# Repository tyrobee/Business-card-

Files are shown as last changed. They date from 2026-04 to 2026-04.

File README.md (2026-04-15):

# Business-card-
A PCB Business card
A personal Business Card designed as a PCB. It contains an integrated NFC tag to share contact information wirelessly, and uses energy harvesting from NFC field to light up the LED circuitry.The heart of this PCB is the NFC controller IC, the NT3H1101 from NXP Semiconductors.NFC (Near Field Communication) is a short-range radio technology that enables communication between devices that are held in close proximity (< 10 cm). NFC systems are based on traditional High Frequency (HF) RFID, operating at 13.56 MHz.The form factor is maintained as a standard credit/debit card, so you can carry it around normally in your wallet.I used the "Bitmap to Component Convertor" tool built in KiCAD to import my custom font text, Logo, QR code, etc. I imported them as Soldermask and Copper layer so that they'll be visible with nice HASL/ENIG finish. My suggestion would be to minimize the use of silkscreen, as the silkscreen print might not be of good quality for complex graphics.The NFC tag programming was done with Tagwriter app from NXP. This app has multiple options to write Website Links, Phone number, Email, etc into the NTAG IC which you can customize as per your requirement.

## Schematics
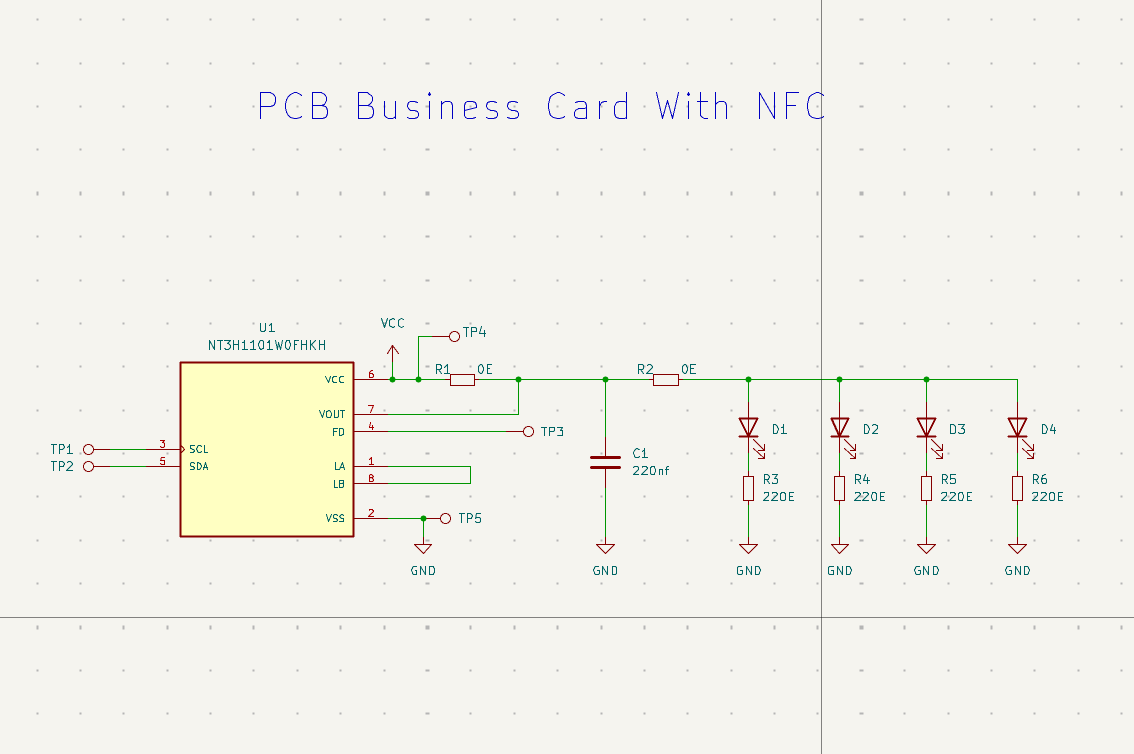
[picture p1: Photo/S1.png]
Back Design


## Pcb 
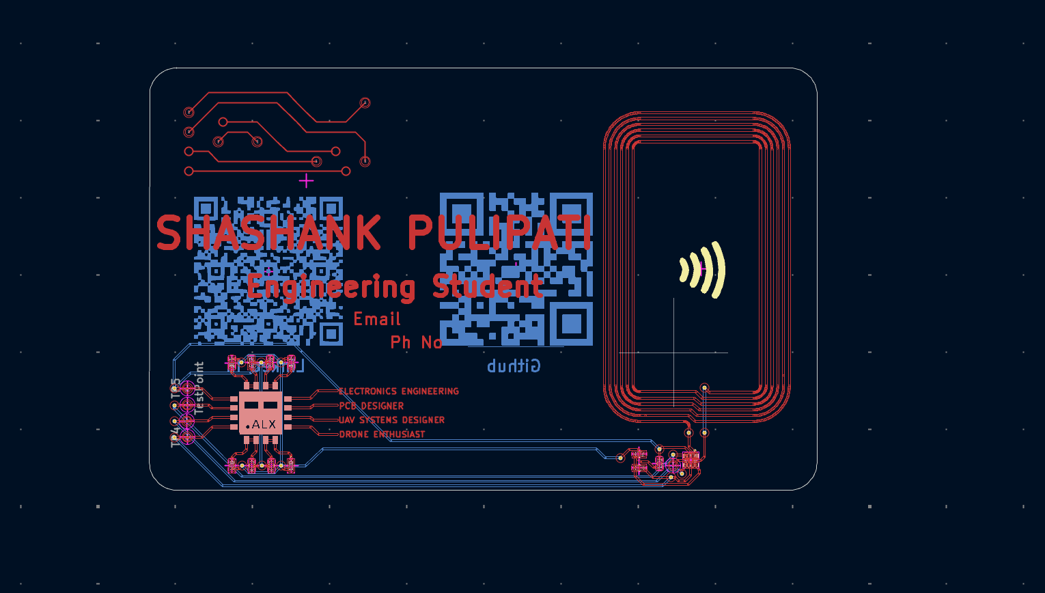
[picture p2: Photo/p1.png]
Front Design


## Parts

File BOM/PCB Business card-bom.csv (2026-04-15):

Name | Purpose | Quantity | Total Cost (USD) | Link | Distributor
pcb and pcba | pcb | 1 | 46.67 |  | jlcpcb

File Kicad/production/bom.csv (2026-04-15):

Designator | Footprint | Quantity | Value | LCSC Part #
C1 | 0402 | 1 | 220nf
D1, D2, D3, D4 | 0402 | 4 | LED
R1, R2 | 0402 | 2 | 0E
R3, R4, R5, R6 | 0402 | 4 | 220E
TP1, TP2, TP3, TP4, TP5 | TestPoint_Pad_D1.0mm | 5 | TestPoint
U1 | IC_NT3H1101W0FHKH | 1 | NT3H1101W0FHKH

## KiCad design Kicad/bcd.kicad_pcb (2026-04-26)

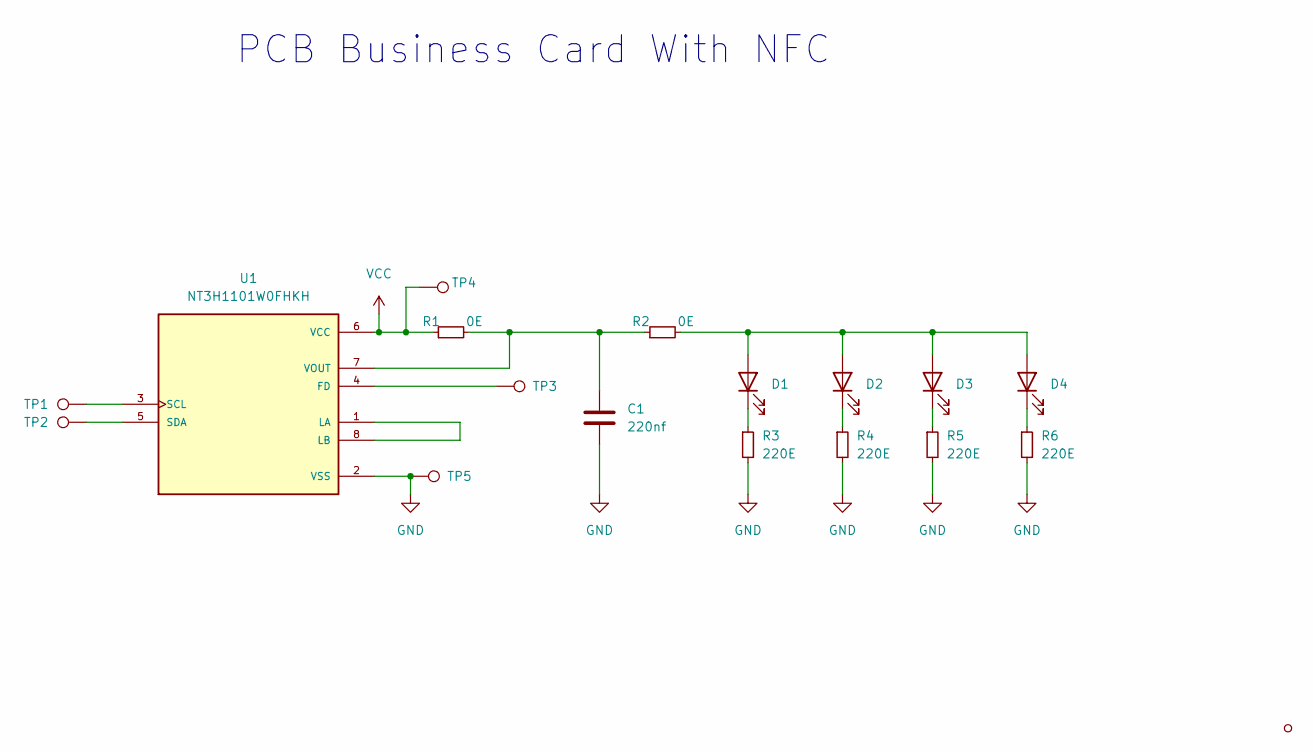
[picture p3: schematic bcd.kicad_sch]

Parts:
C1: 220nf; C_0402_1005Metric
D1, D2, D3, D4: LED; LED_0402_1005Metric
R1, R2: 0E; R_0402_1005Metric
R3, R4, R5, R6: 220E; R_0402_1005Metric
TP1, TP2, TP3, TP4, TP5: TestPoint; TestPoint_Pad_D1.0mm
TP6: TestPoint_Small
U1: NT3H1101W0FHKH; IC_NT3H1101W0FHKH; PARTREV 3.3

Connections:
GND: C1.2, R3.2, R4.2, R5.2, R6.2, TP5.1, U1.2 (VSS)
unnamed: C1.1, R1.2, R2.1, U1.7 (VOUT)
unnamed: D1.1 (K), R3.1
unnamed: D1.2 (A), D2.2 (A), D3.2 (A), D4.2 (A), R2.2
unnamed: D2.1 (K), R4.1
unnamed: D3.1 (K), R5.1
unnamed: D4.1 (K), R6.1
unnamed: TP1.1, U1.3 (SCL)
unnamed: TP2.1, U1.5 (SDA)
unnamed: TP3.1, U1.4 (FD)
unnamed: U1.1 (LA), U1.8 (LB)
VCC: R1.1, TP4.1, U1.6 (VCC)

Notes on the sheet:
PCB Business Card With NFC

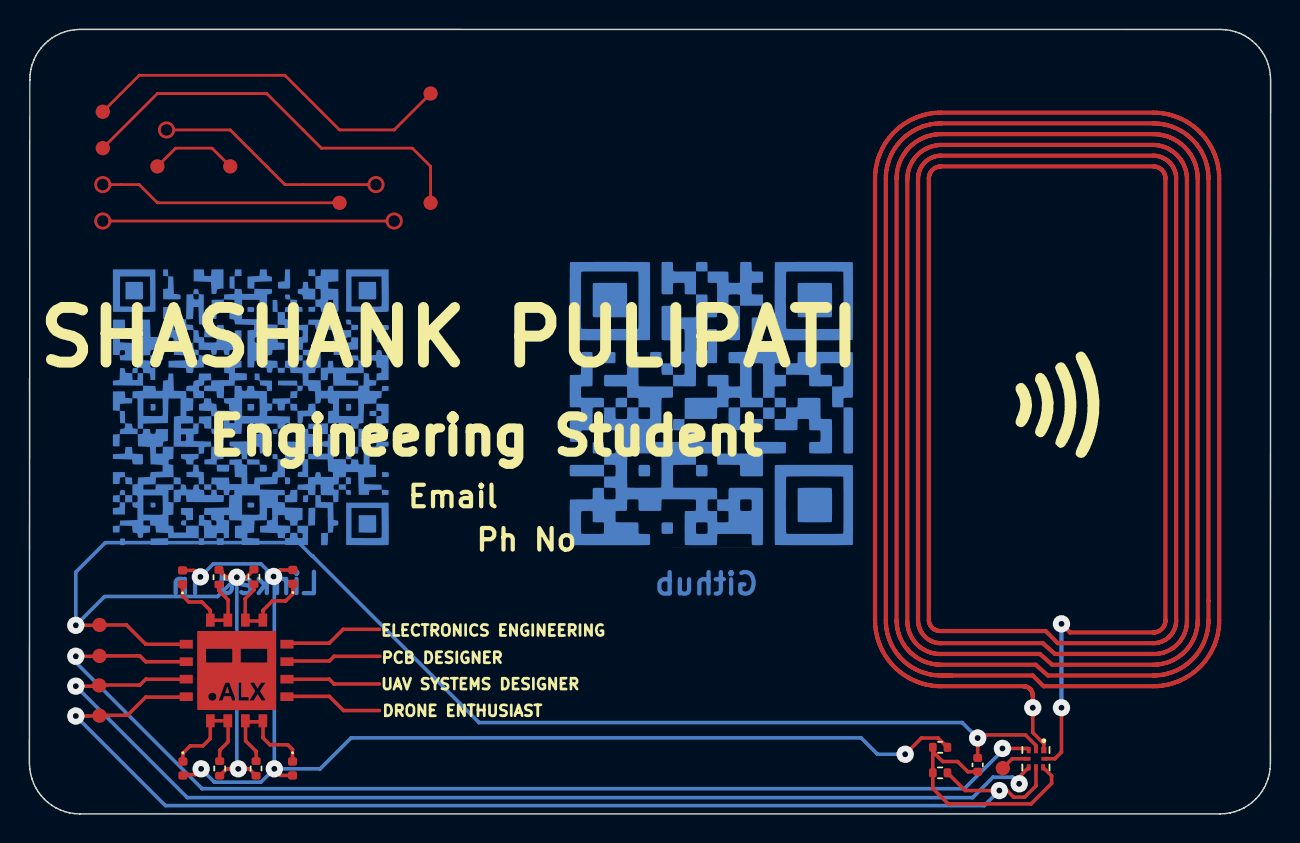
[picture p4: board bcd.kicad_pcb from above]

Board: 2 copper layers, 86.6 x 54.7 mm, 17 parts (0 on the bottom side), 12 nets.
